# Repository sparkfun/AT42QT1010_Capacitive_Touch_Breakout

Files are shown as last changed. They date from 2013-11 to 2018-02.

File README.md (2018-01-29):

SparkFun Capacitive Touch Breakout - AT42QT101X
====================================

<table class="table table-hover table-striped table-bordered">
  <tr>
   <td><a href="https://www.sparkfun.com/products/12041"><div align="center">SparkFun Capacitive Touch Breakout - AT42QT1010</div></a></td>
  <td><a href="https://www.sparkfun.com/products/14520"><div align="center">SparkFun Capacitive Touch Breakout - AT42QT1011</div></a></center></td>
  </tr>
  <tr>
    <td><div align="center">SparkFun Capacitive Touch Breakout - AT42QT1010 [<a href="https://www.sparkfun.com/products/12041">SEN-12041</a>]</div></td>
    <td><div align="center">SparkFun Capacitive Touch Breakout - AT42QT1011 [<a href="https://www.sparkfun.com/products/14520">SEN-14520</a>]</div></td>
  </tr>
</table>

If you need to add user input without using a button, then a capacitive touch interface might be the answer. The AT42QT1010 and AT42QT1011 Capacitive Touch Breakout boards offer a single capacitive touch button with easy-to-use digital I/O pins. Each model features a slightly different output duration.

Repository Contents
-------------------
* **/Documentation** - Datasheet
* **/Firmware** - Example Arduino sketches
* **/Hardware** - All Eagle design files (.brd, .sch, .STL)
* **/Libraries** - Eagle part library
* **/Production** - Test bed files and production panel files

Documentation
-------------------

* **[Hookup Guide](https://learn.sparkfun.com/tutorials/at42qt101x-capacitive-touch-breakout-hookup-guide)** - Basic hookup guide for the AT42QT1010 and AT42QT1011 Capacitive Touch Breakout.
* *[Hookup Guide (RETIRED)](https://learn.sparkfun.com/tutorials/at42qt1010-capacitive-touch-breakout-hookup-guide) - Basic hookup guide for the AT42QT1010 Capacitive Touch Breakout.*
* **[SparkFun Fritzing repo](https://github.com/sparkfun/Fritzing_Parts)** - Fritzing diagrams for SparkFun products.

Version History
---------------
* **HW_v20.0_FW_v1.0** - Current Version for AT42QT1010 and AT42QT1011 with 8-pin UDFN/USON package.
* *[HW_v1.0_FW_v1.0 (RETIRED)](https://github.com/sparkfun/AT42QT1010_Capacitive_Touch_Breakout/releases/tag/HW_v1.0_FW_v1.0) - Initial release for the AT42QT1010 with 6-Pin SOT23-6 package.*

License Information
-------------------

This product is _**open source**_! 

Please review the LICENSE.md file for license information. 

If you have any questions or concerns on licensing, please contact techsupport@sparkfun.com.

Distributed as-is; no warranty is given.

- Your friends at SparkFun.

_<COLLABORATION CREDIT>_

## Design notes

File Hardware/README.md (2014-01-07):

# What Are these Files?

The .sch and .brd files hare are Eagle CAD schematic and PCB design files.

These files were created with Eagle 6.5.0, you'll need Eagle 6.5 or later to open them up. There is a free, lite, version of Eagle available from [cadsoftusa.com](cadsoftusa.com).

# License

This product is open source! These Eagle files are released under the Creative Commons Share-Alike Attribution license ([CC BY-SA 3.0](http://creativecommons.org/licenses/by-sa/3.0/us/)).

Please use, reuse, and modify these files as you see fit. Please maintain attribution and release anything derivative under the same license.

- Your friends at SparkFun.

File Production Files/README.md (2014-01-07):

These are the production files SparkFun uses for printing PCBs, as well as the Eagle files for our test beds.

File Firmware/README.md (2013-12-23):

* AT42QT1010_Arduino_Example - Simple sketch showing how to use the AT42QT1010 to detect a capacitive touch event

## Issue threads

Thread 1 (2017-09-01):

Prototype quality review

marshalltaylorSFE, 2017-09-01:
## Board:
1.  Rogue tRestrict box floating at (0.965 ,0.385)in.  I think it needs to be removed

2.  NPTH callout belongs in "Special ordering instructions" box, which has schematic symbol.  Layout object goes center under CC attrib

3.  Match name text font and weight on CC in layout.  Names should match style of CC text

4.  Improve measures-

* Move to measures layer
* Text -> vector
* Remove "typ."
* Call out lower holes as well

5.  Jumper text L and F should be separated more and balanced so they don't look like "LF"

6.  Change 19% ratio on connector pins (4 pin header) to 15%

7.  Move large flame off button -- We may have discussed this but looking again, it needs to not be there.  Let me know if you have questions.

## Schematic:
8.  Make flags 0.05 inch, vector, 15%

## General:

9.  Parts not in sparkfun-eagle-libraries or local_library:

* Stand-off
* 1 pin holes (connectors)
* Weird 1 pin SMD pad
* 4-pin right angle SMD connectors
* Power symbols
* Ground symbols

10.  Parts not in bom:

* New PCB (still has old)
* New IC (still has old)

11.  Optional, 4 single pins could be smashed, values removed.
Recommend switching to 4 pin 0.1 inch header rather than 4 1pins

12.  LED color selected as green because it's a button.  This is against standard but not a problem

13.  LED not labeled with purpose- OK, purpose is obvious

edspark, 2017-09-01:
1. Correct
2. Now that I understand what that is, it has been fixed
3. Fixed
4. Fixed
5. Seperated them as best as possible. Added a dash as well.
6. Fixed
7. I put the best fit flame I could on the other side.
8. Persistent Vector setting...never again.,
9. Fixed.
10. Created new PCB but we're keeping current SKU for this revision.  The IC and PCB will stay under their old SKU's until we're ready for REDS.
11. Fixed
12. Werd
13. Actually laughed out loud.

Closed 2017-09-01.

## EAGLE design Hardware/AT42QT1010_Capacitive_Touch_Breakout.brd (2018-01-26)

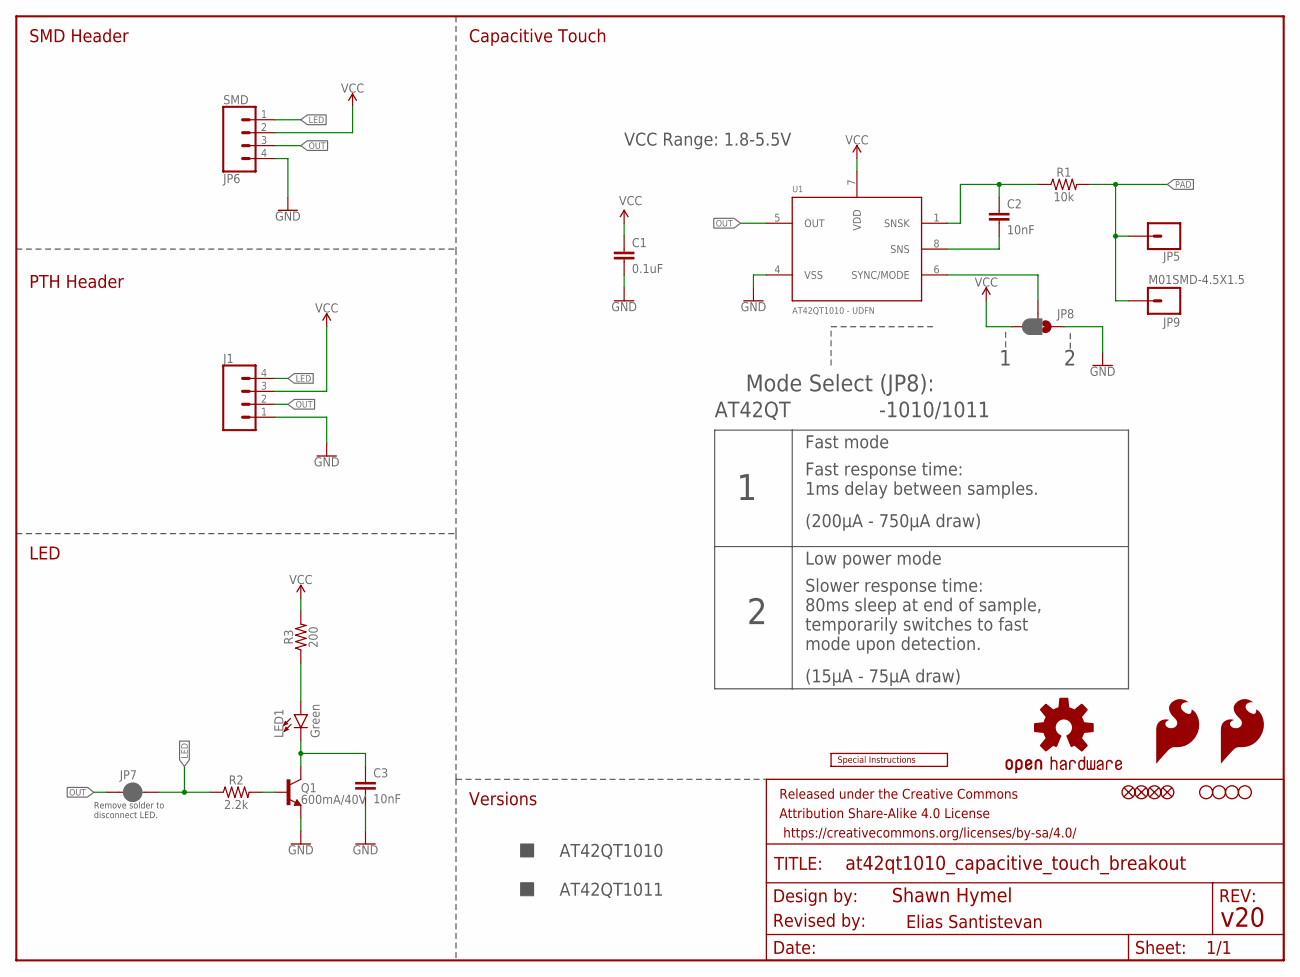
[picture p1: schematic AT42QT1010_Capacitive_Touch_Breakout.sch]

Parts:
C1: 0.1uF; 0603
C2, C3: 10nF; 0603
FID1, FID2, FID3, FID4: FIDUCIAL1X2; FIDUCIAL-1X2
FRAME1: FRAME-LETTER; CREATIVE_COMMONS
J1: CONN_04; 1X04
JP5: CONN_01; 1X01
JP6: SMD; 1X04_SMD_RA_MALE
JP7: JUMPER-SMT_2_NC_PASTE_SILK; SMT-JUMPER_2_NC_PASTE_SILK
JP8: JUMPER-SMT_3_1-NC_PASTE_SILK; SMT-JUMPER_3_1-NC_PASTE_SILK
JP9: M01SMD-4.5X1.5; PAD-1.5X4.5
LED1: Green; LED-1206-BOTTOM
LOGO1, LOGO4: SFE_LOGO_FLAME.2_INCH; SFE_LOGO_FLAME_.2
LOGO2: OSHW-LOGOS; OSHW-LOGO-S
Q1: 600mA/40V; SOT23-3
R1: 10k; 0603
R2: 2.2k; 0603
R3: 200; 0603
STANDOFF1, STANDOFF2, STANDOFF3, STANDOFF4: STAND-OFF
U1: AT42QT1010 - UDFN; UDFN/USON_8_PAD
U$1: SPECIAL_INSTRUCTIONS-ORDERING; ORDERING_INSTRUCTIONS

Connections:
GND: C1.2, C3.2, J1.1, JP6.4, JP8.1, Q1.2 (E), U1.4 (VSS)
LED: J1.4, JP6.1, JP7.2, R2.1
unnamed: JP8.2, U1.6 (SYNC/MODE)
unnamed: C2.2, U1.8 (SNS)
unnamed: C2.1, R1.1, U1.1 (SNSK)
unnamed: Q1.1 (B), R2.2
unnamed: C3.1, LED1.C, Q1.3 (C)
unnamed: LED1.A, R3.1
OUT: J1.2, JP6.3, JP7.1, U1.5 (OUT)
PAD: JP5.1, JP9.P$1, R1.2
VCC: C1.1, J1.3, JP6.2, JP8.3, R3.2, U1.7 (VDD)

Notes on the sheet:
Shawn Hymel
v20
Capacitive Touch
SMD Header
PTH Header
LED
-1010/1011
Fast mode
Fast response time: 1ms delay between samples.
Low power mode
(15µA - 75µA draw)
Slower response time: 80ms sleep at end of sample, temporarily switches to fast mode upon detection.
(200µA - 750µA draw)
Revised by:
Elias Santistevan
VCC Range: 1.8-5.5V
Remove solder to disconnect LED.
Mode Select (JP8):
AT42QT
Versions
AT42QT1010
AT42QT1011

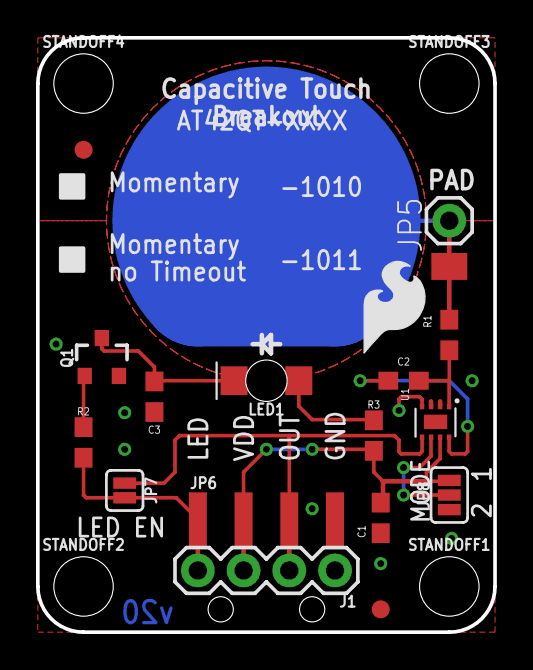
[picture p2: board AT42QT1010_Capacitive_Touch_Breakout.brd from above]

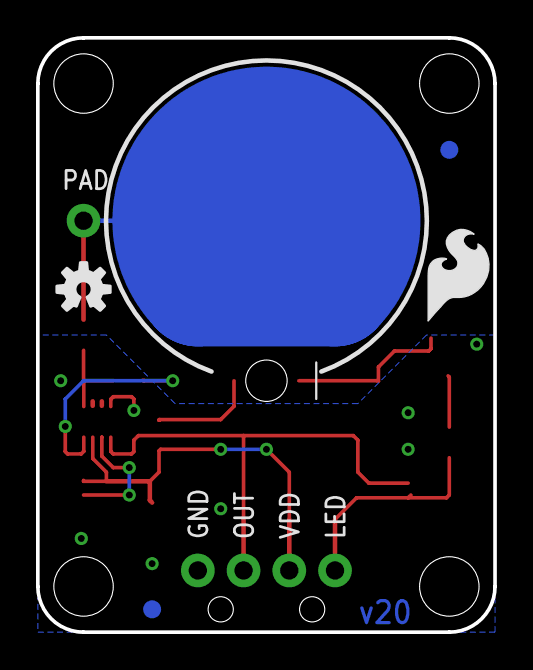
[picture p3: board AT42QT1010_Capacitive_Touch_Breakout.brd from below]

Board: 2 copper layers, 25.4 x 33.0 mm, 28 parts (4 on the bottom side), 11 nets.

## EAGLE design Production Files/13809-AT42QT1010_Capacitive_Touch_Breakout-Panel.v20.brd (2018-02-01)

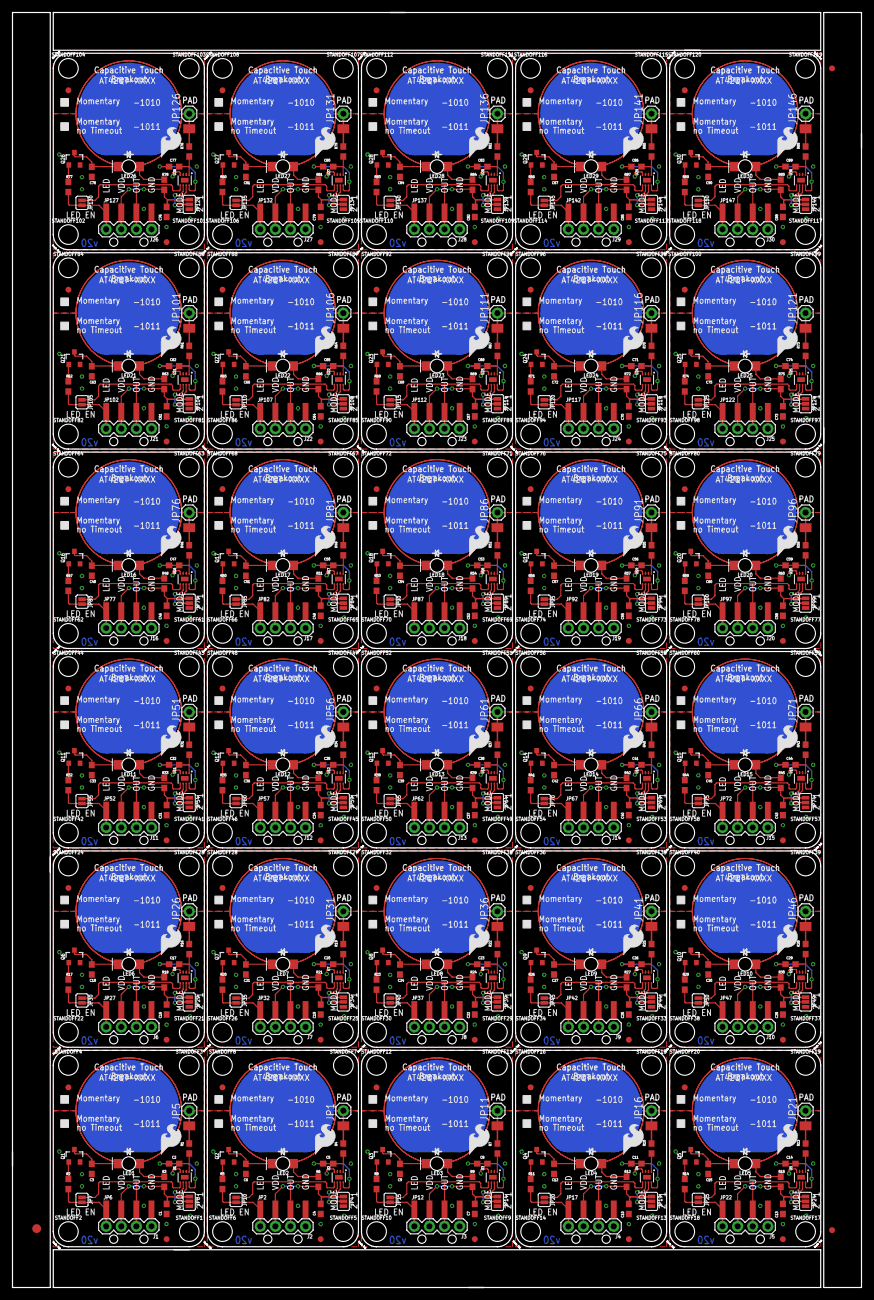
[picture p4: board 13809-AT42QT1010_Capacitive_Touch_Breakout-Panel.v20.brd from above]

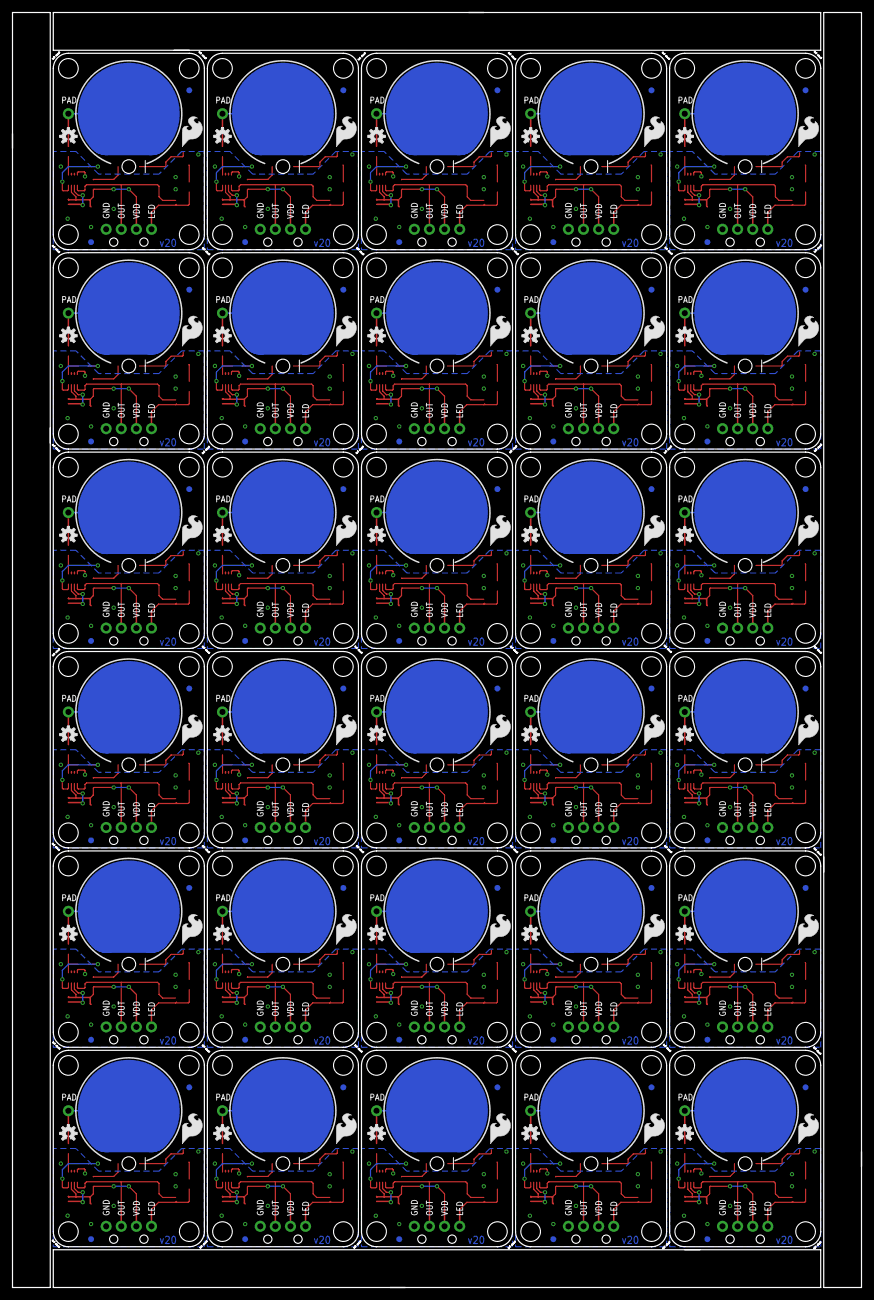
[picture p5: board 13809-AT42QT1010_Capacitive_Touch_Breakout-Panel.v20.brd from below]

Board: 2 copper layers, 142.7 x 214.4 mm, 783 parts (120 on the bottom side), 330 nets.

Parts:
C1, C4, C7, C10, C13, C16, C19, C22, C25, C28, C31, C34, C37, C40, C43, C46, C49, C52, C55, C58, C61, C64, C67, C70, C73, C76, C79, C82, C85, C88: 0.1uF; 0603
C2, C3, C5, C6, C8, C9, C11, C12, C14, C15, C17, C18, C20, C21, C23, C24, C26, C27, C29, C30, C32, C33, C35, C36, C38, C39, C41, C42, C44, C45, C47, C48, C50, C51, C53, C54, C56, C57, C59, C60, C62, C63, C65, C66, C68, C69, C71, C72, C74, C75, C77, C78, C80, C81, C83, C84, C86, C87, C89, C90: 10nF; 0603
E$1: FIDUCIAL-1.5X3
E$7, E$8: FIDUCIAL-1X2
FID1, FID2, FID3, FID4, FID5, FID6, FID7, FID8, FID9, FID10, FID11, FID12, FID13, FID14, FID15, FID16, FID17, FID18, FID19, FID20, FID21, FID22, FID23, FID24, FID25, FID26, FID27, FID28, FID29, FID30, FID31, FID32, FID33, FID34, FID35, FID36, FID37, FID38, FID39, FID40, FID41, FID42, FID43, FID44, FID45, FID46, FID47, FID48, FID49, FID50, FID51, FID52, FID53, FID54, FID55, FID56, FID57, FID58, FID59, FID60, FID61, FID62, FID63, FID64, FID65, FID66, FID67, FID68, FID69, FID70, FID71, FID72, FID73, FID74, FID75, FID76, FID77, FID78, FID79, FID80, FID81, FID82, FID83, FID84, FID85, FID86, FID87, FID88, FID89, FID90, FID91, FID92, FID93, FID94, FID95, FID96, FID97, FID98, FID99, FID100, FID101, FID102, FID103, FID104, FID105, FID106, FID107, FID108, FID109, FID110, FID111, FID112, FID113, FID114, FID115, FID116, FID117, FID118, FID119, FID120: FIDUCIAL1X2; FIDUCIAL-1X2
J1, J2, J3, J4, J5, J6, J7, J8, J9, J10, J11, J12, J13, J14, J15, J16, J17, J18, J19, J20, J21, J22, J23, J24, J25, J26, J27, J28, J29, J30: 1X04
JP1, JP5, JP11, JP16, JP21, JP26, JP31, JP36, JP41, JP46, JP51, JP56, JP61, JP66, JP71, JP76, JP81, JP86, JP91, JP96, JP101, JP106, JP111, JP116, JP121, JP126, JP131, JP136, JP141, JP146: 1X01
JP2, JP6, JP12, JP17, JP22, JP27, JP32, JP37, JP42, JP47, JP52, JP57, JP62, JP67, JP72, JP77, JP82, JP87, JP92, JP97, JP102, JP107, JP112, JP117, JP122, JP127, JP132, JP137, JP142, JP147: SMD; 1X04_SMD_RA_MALE
JP3, JP9, JP13, JP18, JP23, JP28, JP33, JP38, JP43, JP48, JP53, JP58, JP63, JP68, JP73, JP78, JP83, JP88, JP93, JP98, JP103, JP108, JP113, JP118, JP123, JP128, JP133, JP138, JP143, JP148: M01SMD-4.5X1.5; PAD-1.5X4.5
JP4, JP8, JP14, JP19, JP24, JP29, JP34, JP39, JP44, JP49, JP54, JP59, JP64, JP69, JP74, JP79, JP84, JP89, JP94, JP99, JP104, JP109, JP114, JP119, JP124, JP129, JP134, JP139, JP144, JP149: JUMPER-SMT_3_NO_SILK; SMT-JUMPER_3_NO_SILK
JP7, JP10, JP15, JP20, JP25, JP30, JP35, JP40, JP45, JP50, JP55, JP60, JP65, JP70, JP75, JP80, JP85, JP90, JP95, JP100, JP105, JP110, JP115, JP120, JP125, JP130, JP135, JP140, JP145, JP150: JUMPER-SMT_2_NO_SILK; SMT-JUMPER_2_NO_SILK
LED1, LED2, LED3, LED4, LED5, LED6, LED7, LED8, LED9, LED10, LED11, LED12, LED13, LED14, LED15, LED16, LED17, LED18, LED19, LED20, LED21, LED22, LED23, LED24, LED25, LED26, LED27, LED28, LED29, LED30: Green; LED-1206-BOTTOM
LOGO1, LOGO4, LOGO5, LOGO6, LOGO8, LOGO9, LOGO11, LOGO12, LOGO14, LOGO15, LOGO17, LOGO18, LOGO20, LOGO21, LOGO23, LOGO24, LOGO26, LOGO27, LOGO29, LOGO30, LOGO32, LOGO33, LOGO35, LOGO36, LOGO38, LOGO39, LOGO41, LOGO42, LOGO44, LOGO45, LOGO47, LOGO48, LOGO50, LOGO51, LOGO53, LOGO54, LOGO56, LOGO57, LOGO59, LOGO60, LOGO62, LOGO63, LOGO65, LOGO66, LOGO68, LOGO69, LOGO71, LOGO72, LOGO74, LOGO75, LOGO77, LOGO78, LOGO80, LOGO81, LOGO83, LOGO84, LOGO86, LOGO87, LOGO89, LOGO90: SFE_LOGO_FLAME.2_INCH; SFE_LOGO_FLAME_.2
LOGO2, LOGO3, LOGO7, LOGO10, LOGO13, LOGO16, LOGO19, LOGO22, LOGO25, LOGO28, LOGO31, LOGO34, LOGO37, LOGO40, LOGO43, LOGO46, LOGO49, LOGO52, LOGO55, LOGO58, LOGO61, LOGO64, LOGO67, LOGO70, LOGO73, LOGO76, LOGO79, LOGO82, LOGO85, LOGO88: OSHW-LOGOS; OSHW-LOGO-S
Q1, Q2, Q3, Q4, Q5, Q6, Q7, Q8, Q9, Q10, Q11, Q12, Q13, Q14, Q15, Q16, Q17, Q18, Q19, Q20, Q21, Q22, Q23, Q24, Q25, Q26, Q27, Q28, Q29, Q30: 600mA/40V; SOT23-3
R1, R4, R7, R10, R13, R16, R19, R22, R25, R28, R31, R34, R37, R40, R43, R46, R49, R52, R55, R58, R61, R64, R67, R70, R73, R76, R79, R82, R85, R88: 10k; 0603
R2, R5, R8, R11, R14, R17, R20, R23, R26, R29, R32, R35, R38, R41, R44, R47, R50, R53, R56, R59, R62, R65, R68, R71, R74, R77, R80, R83, R86, R89: 2.2k; 0603
R3, R6, R9, R12, R15, R18, R21, R24, R27, R30, R33, R36, R39, R42, R45, R48, R51, R54, R57, R60, R63, R66, R69, R72, R75, R78, R81, R84, R87, R90: 200; 0603
STANDOFF1, STANDOFF2, STANDOFF3, STANDOFF4, STANDOFF5, STANDOFF6, STANDOFF7, STANDOFF8, STANDOFF9, STANDOFF10, STANDOFF11, STANDOFF12, STANDOFF13, STANDOFF14, STANDOFF15, STANDOFF16, STANDOFF17, STANDOFF18, STANDOFF19, STANDOFF20, STANDOFF21, STANDOFF22, STANDOFF23, STANDOFF24, STANDOFF25, STANDOFF26, STANDOFF27, STANDOFF28, STANDOFF29, STANDOFF30, STANDOFF31, STANDOFF32, STANDOFF33, STANDOFF34, STANDOFF35, STANDOFF36, STANDOFF37, STANDOFF38, STANDOFF39, STANDOFF40, STANDOFF41, STANDOFF42, STANDOFF43, STANDOFF44, STANDOFF45, STANDOFF46, STANDOFF47, STANDOFF48, STANDOFF49, STANDOFF50, STANDOFF51, STANDOFF52, STANDOFF53, STANDOFF54, STANDOFF55, STANDOFF56, STANDOFF57, STANDOFF58, STANDOFF59, STANDOFF60, STANDOFF61, STANDOFF62, STANDOFF63, STANDOFF64, STANDOFF65, STANDOFF66, STANDOFF67, STANDOFF68, STANDOFF69, STANDOFF70, STANDOFF71, STANDOFF72, STANDOFF73, STANDOFF74, STANDOFF75, STANDOFF76, STANDOFF77, STANDOFF78, STANDOFF79, STANDOFF80, STANDOFF81, STANDOFF82, STANDOFF83, STANDOFF84, STANDOFF85, STANDOFF86, STANDOFF87, STANDOFF88, STANDOFF89, STANDOFF90, STANDOFF91, STANDOFF92, STANDOFF93, STANDOFF94, STANDOFF95, STANDOFF96, STANDOFF97, STANDOFF98, STANDOFF99, STANDOFF100, STANDOFF101, STANDOFF102, STANDOFF103, STANDOFF104, STANDOFF105, STANDOFF106, STANDOFF107, STANDOFF108, STANDOFF109, STANDOFF110, STANDOFF111, STANDOFF112, STANDOFF113, STANDOFF114, STANDOFF115, STANDOFF116, STANDOFF117, STANDOFF118, STANDOFF119, STANDOFF120: STAND-OFF
U1, U2, U3, U4, U5, U6, U7, U8, U9, U10, U11, U12, U13, U14, U15, U16, U17, U18, U19, U20, U21, U22, U23, U24, U25, U26, U27, U28, U29, U30: AT42QT1010 - UDFN; UDFN/USON_8_PAD

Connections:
GND: C1.2, C3.2, J1.1, JP6.4, JP8.3, Q1.2, U1.4
GND1: C4.2, C6.2, J2.1, JP2.4, JP4.3, Q2.2, U2.4
GND2: C7.2, C9.2, J3.1, JP12.4, JP14.3, Q3.2, U3.4
GND3: C10.2, C12.2, J4.1, JP17.4, JP19.3, Q4.2, U4.4
GND4: C13.2, C15.2, J5.1, JP22.4, JP24.3, Q5.2, U5.4
GND5: C16.2, C18.2, J6.1, JP27.4, JP29.3, Q6.2, U6.4
GND6: C19.2, C21.2, J7.1, JP32.4, JP34.3, Q7.2, U7.4
GND7: C22.2, C24.2, J8.1, JP37.4, JP39.3, Q8.2, U8.4
GND8: C25.2, C27.2, J9.1, JP42.4, JP44.3, Q9.2, U9.4
GND9: C28.2, C30.2, J10.1, JP47.4, JP49.3, Q10.2, U10.4
GND10: C31.2, C33.2, J11.1, JP52.4, JP54.3, Q11.2, U11.4
GND11: C34.2, C36.2, J12.1, JP57.4, JP59.3, Q12.2, U12.4
GND12: C37.2, C39.2, J13.1, JP62.4, JP64.3, Q13.2, U13.4
GND13: C40.2, C42.2, J14.1, JP67.4, JP69.3, Q14.2, U14.4
GND14: C43.2, C45.2, J15.1, JP72.4, JP74.3, Q15.2, U15.4
GND15: C46.2, C48.2, J16.1, JP77.4, JP79.3, Q16.2, U16.4
GND16: C49.2, C51.2, J17.1, JP82.4, JP84.3, Q17.2, U17.4
GND17: C52.2, C54.2, J18.1, JP87.4, JP89.3, Q18.2, U18.4
GND18: C55.2, C57.2, J19.1, JP92.4, JP94.3, Q19.2, U19.4
GND19: C58.2, C60.2, J20.1, JP97.4, JP99.3, Q20.2, U20.4
GND20: C61.2, C63.2, J21.1, JP102.4, JP104.3, Q21.2, U21.4
GND21: C64.2, C66.2, J22.1, JP107.4, JP109.3, Q22.2, U22.4
GND22: C67.2, C69.2, J23.1, JP112.4, JP114.3, Q23.2, U23.4
GND23: C70.2, C72.2, J24.1, JP117.4, JP119.3, Q24.2, U24.4
GND24: C73.2, C75.2, J25.1, JP122.4, JP124.3, Q25.2, U25.4
GND25: C76.2, C78.2, J26.1, JP127.4, JP129.3, Q26.2, U26.4
GND26: C79.2, C81.2, J27.1, JP132.4, JP134.3, Q27.2, U27.4
GND27: C82.2, C84.2, J28.1, JP137.4, JP139.3, Q28.2, U28.4
GND28: C85.2, C87.2, J29.1, JP142.4, JP144.3, Q29.2, U29.4
GND29: C88.2, C90.2, J30.1, JP147.4, JP149.3, Q30.2, U30.4
LED: J1.4, JP6.1, JP7.2, R2.1
LED1: J2.4, JP2.1, JP10.2, R5.1
LED2: J3.4, JP12.1, JP15.2, R8.1
LED3: J4.4, JP17.1, JP20.2, R11.1
LED4: J5.4, JP22.1, JP25.2, R14.1
LED5: J6.4, JP27.1, JP30.2, R17.1
LED6: J7.4, JP32.1, JP35.2, R20.1
LED7: J8.4, JP37.1, JP40.2, R23.1
LED8: J9.4, JP42.1, JP45.2, R26.1
LED9: J10.4, JP47.1, JP50.2, R29.1
LED10: J11.4, JP52.1, JP55.2, R32.1
LED11: J12.4, JP57.1, JP60.2, R35.1
LED12: J13.4, JP62.1, JP65.2, R38.1
LED13: J14.4, JP67.1, JP70.2, R41.1
LED14: J15.4, JP72.1, JP75.2, R44.1
LED15: J16.4, JP77.1, JP80.2, R47.1
LED16: J17.4, JP82.1, JP85.2, R50.1
LED17: J18.4, JP87.1, JP90.2, R53.1
LED18: J19.4, JP92.1, JP95.2, R56.1
LED19: J20.4, JP97.1, JP100.2, R59.1
LED20: J21.4, JP102.1, JP105.2, R62.1
LED21: J22.4, JP107.1, JP110.2, R65.1
LED22: J23.4, JP112.1, JP115.2, R68.1
LED23: J24.4, JP117.1, JP120.2, R71.1
LED24: J25.4, JP122.1, JP125.2, R74.1
LED25: J26.4, JP127.1, JP130.2, R77.1
LED26: J27.4, JP132.1, JP135.2, R80.1
LED27: J28.4, JP137.1, JP140.2, R83.1
LED28: J29.4, JP142.1, JP145.2, R86.1
LED29: J30.4, JP147.1, JP150.2, R89.1
unnamed: C5.2, U2.8
unnamed: C2.2, U1.8
unnamed: C2.1, R1.1, U1.1
unnamed: C5.1, R4.1, U2.1
unnamed: JP8.2, U1.6
unnamed: JP4.2, U2.6
unnamed: Q2.1, R5.2
unnamed: Q1.1, R2.2
unnamed: C3.1, LED1.C, Q1.3
unnamed: LED1.A, R3.1
unnamed: C6.1, LED2.C, Q2.3
unnamed: LED2.A, R6.1
unnamed: C8.2, U3.8
unnamed: C8.1, R7.1, U3.1
unnamed: JP14.2, U3.6
unnamed: Q3.1, R8.2
unnamed: C9.1, LED3.C, Q3.3
unnamed: LED3.A, R9.1
unnamed: C11.2, U4.8
unnamed: C11.1, R10.1, U4.1
unnamed: JP19.2, U4.6
unnamed: Q4.1, R11.2
unnamed: C12.1, LED4.C, Q4.3
unnamed: LED4.A, R12.1
unnamed: C14.2, U5.8
unnamed: C14.1, R13.1, U5.1
unnamed: JP24.2, U5.6
unnamed: Q5.1, R14.2
unnamed: C15.1, LED5.C, Q5.3
unnamed: LED5.A, R15.1
unnamed: C17.2, U6.8
unnamed: C17.1, R16.1, U6.1
unnamed: JP29.2, U6.6
unnamed: Q6.1, R17.2
unnamed: C18.1, LED6.C, Q6.3
unnamed: LED6.A, R18.1
unnamed: C20.2, U7.8
unnamed: C20.1, R19.1, U7.1
unnamed: JP34.2, U7.6
unnamed: Q7.1, R20.2
unnamed: C21.1, LED7.C, Q7.3
unnamed: LED7.A, R21.1
unnamed: C23.2, U8.8
unnamed: C23.1, R22.1, U8.1
unnamed: JP39.2, U8.6
unnamed: Q8.1, R23.2
unnamed: C24.1, LED8.C, Q8.3
unnamed: LED8.A, R24.1
unnamed: C26.2, U9.8
unnamed: C26.1, R25.1, U9.1
unnamed: JP44.2, U9.6
unnamed: Q9.1, R26.2
unnamed: C27.1, LED9.C, Q9.3
unnamed: LED9.A, R27.1
unnamed: C29.2, U10.8
unnamed: C29.1, R28.1, U10.1
unnamed: JP49.2, U10.6
unnamed: Q10.1, R29.2
unnamed: C30.1, LED10.C, Q10.3
unnamed: LED10.A, R30.1
unnamed: C32.2, U11.8
unnamed: C32.1, R31.1, U11.1
unnamed: JP54.2, U11.6
unnamed: Q11.1, R32.2
unnamed: C33.1, LED11.C, Q11.3
unnamed: LED11.A, R33.1
unnamed: C35.2, U12.8
unnamed: C35.1, R34.1, U12.1
unnamed: JP59.2, U12.6
unnamed: Q12.1, R35.2
unnamed: C36.1, LED12.C, Q12.3
unnamed: LED12.A, R36.1
unnamed: C38.2, U13.8
unnamed: C38.1, R37.1, U13.1
unnamed: JP64.2, U13.6
unnamed: Q13.1, R38.2
unnamed: C39.1, LED13.C, Q13.3
unnamed: LED13.A, R39.1
unnamed: C41.2, U14.8
unnamed: C41.1, R40.1, U14.1
unnamed: JP69.2, U14.6
unnamed: Q14.1, R41.2
unnamed: C42.1, LED14.C, Q14.3
unnamed: LED14.A, R42.1
unnamed: C44.2, U15.8
unnamed: C44.1, R43.1, U15.1
unnamed: JP74.2, U15.6
unnamed: Q15.1, R44.2
unnamed: C45.1, LED15.C, Q15.3
unnamed: LED15.A, R45.1
unnamed: C47.2, U16.8
unnamed: C47.1, R46.1, U16.1
unnamed: JP79.2, U16.6
unnamed: Q16.1, R47.2
unnamed: C48.1, LED16.C, Q16.3
unnamed: LED16.A, R48.1
unnamed: C50.2, U17.8
unnamed: C50.1, R49.1, U17.1
unnamed: JP84.2, U17.6
unnamed: Q17.1, R50.2
unnamed: C51.1, LED17.C, Q17.3
unnamed: LED17.A, R51.1
unnamed: C53.2, U18.8
unnamed: C53.1, R52.1, U18.1
unnamed: JP89.2, U18.6
unnamed: Q18.1, R53.2
unnamed: C54.1, LED18.C, Q18.3
unnamed: LED18.A, R54.1
unnamed: C56.2, U19.8
unnamed: C56.1, R55.1, U19.1
unnamed: JP94.2, U19.6
unnamed: Q19.1, R56.2
unnamed: C57.1, LED19.C, Q19.3
unnamed: LED19.A, R57.1
unnamed: C59.2, U20.8
unnamed: C59.1, R58.1, U20.1
unnamed: JP99.2, U20.6
unnamed: Q20.1, R59.2
unnamed: C60.1, LED20.C, Q20.3
unnamed: LED20.A, R60.1
unnamed: C62.2, U21.8
unnamed: C62.1, R61.1, U21.1
unnamed: JP104.2, U21.6
unnamed: Q21.1, R62.2
unnamed: C63.1, LED21.C, Q21.3
unnamed: LED21.A, R63.1
unnamed: C65.2, U22.8
unnamed: C65.1, R64.1, U22.1
unnamed: JP109.2, U22.6
unnamed: Q22.1, R65.2
unnamed: C66.1, LED22.C, Q22.3
unnamed: LED22.A, R66.1
unnamed: C68.2, U23.8
unnamed: C68.1, R67.1, U23.1
unnamed: JP114.2, U23.6
unnamed: Q23.1, R68.2
unnamed: C69.1, LED23.C, Q23.3
unnamed: LED23.A, R69.1
unnamed: C71.2, U24.8
unnamed: C71.1, R70.1, U24.1
unnamed: JP119.2, U24.6
unnamed: Q24.1, R71.2
unnamed: C72.1, LED24.C, Q24.3
unnamed: LED24.A, R72.1
unnamed: C74.2, U25.8
unnamed: C74.1, R73.1, U25.1
unnamed: JP124.2, U25.6
unnamed: Q25.1, R74.2
unnamed: C75.1, LED25.C, Q25.3
unnamed: LED25.A, R75.1
unnamed: C77.2, U26.8
unnamed: C77.1, R76.1, U26.1
unnamed: JP129.2, U26.6
unnamed: Q26.1, R77.2
unnamed: C78.1, LED26.C, Q26.3
unnamed: LED26.A, R78.1
unnamed: C80.2, U27.8
unnamed: C80.1, R79.1, U27.1
unnamed: JP134.2, U27.6
unnamed: Q27.1, R80.2
unnamed: C81.1, LED27.C, Q27.3
unnamed: LED27.A, R81.1
unnamed: C83.2, U28.8
unnamed: C83.1, R82.1, U28.1
unnamed: JP139.2, U28.6
unnamed: Q28.1, R83.2
unnamed: C84.1, LED28.C, Q28.3
unnamed: LED28.A, R84.1
unnamed: C86.2, U29.8
unnamed: C86.1, R85.1, U29.1
unnamed: JP144.2, U29.6
unnamed: Q29.1, R86.2
unnamed: C87.1, LED29.C, Q29.3
unnamed: LED29.A, R87.1
unnamed: C89.2, U30.8
unnamed: C89.1, R88.1, U30.1
unnamed: JP149.2, U30.6
unnamed: Q30.1, R89.2
unnamed: C90.1, LED30.C, Q30.3
unnamed: LED30.A, R90.1
OUT: J1.2, JP6.3, JP7.1, U1.5
OUT1: J2.2, JP2.3, JP10.1, U2.5
OUT2: J3.2, JP12.3, JP15.1, U3.5
OUT3: J4.2, JP17.3, JP20.1, U4.5
OUT4: J5.2, JP22.3, JP25.1, U5.5
OUT5: J6.2, JP27.3, JP30.1, U6.5
OUT6: J7.2, JP32.3, JP35.1, U7.5
OUT7: J8.2, JP37.3, JP40.1, U8.5
OUT8: J9.2, JP42.3, JP45.1, U9.5
OUT9: J10.2, JP47.3, JP50.1, U10.5
OUT10: J11.2, JP52.3, JP55.1, U11.5
OUT11: J12.2, JP57.3, JP60.1, U12.5
OUT12: J13.2, JP62.3, JP65.1, U13.5
OUT13: J14.2, JP67.3, JP70.1, U14.5
OUT14: J15.2, JP72.3, JP75.1, U15.5
OUT15: J16.2, JP77.3, JP80.1, U16.5
OUT16: J17.2, JP82.3, JP85.1, U17.5
OUT17: J18.2, JP87.3, JP90.1, U18.5
OUT18: J19.2, JP92.3, JP95.1, U19.5
OUT19: J20.2, JP97.3, JP100.1, U20.5
OUT20: J21.2, JP102.3, JP105.1, U21.5
OUT21: J22.2, JP107.3, JP110.1, U22.5
OUT22: J23.2, JP112.3, JP115.1, U23.5
OUT23: J24.2, JP117.3, JP120.1, U24.5
OUT24: J25.2, JP122.3, JP125.1, U25.5
OUT25: J26.2, JP127.3, JP130.1, U26.5
OUT26: J27.2, JP132.3, JP135.1, U27.5
OUT27: J28.2, JP137.3, JP140.1, U28.5
OUT28: J29.2, JP142.3, JP145.1, U29.5
OUT29: J30.2, JP147.3, JP150.1, U30.5
PAD: JP5.1, JP9.P$1, R1.2
PAD1: JP1.1, JP3.P$1, R4.2
PAD2: JP11.1, JP13.P$1, R7.2
PAD3: JP16.1, JP18.P$1, R10.2
PAD4: JP21.1, JP23.P$1, R13.2
PAD5: JP26.1, JP28.P$1, R16.2
PAD6: JP31.1, JP33.P$1, R19.2
PAD7: JP36.1, JP38.P$1, R22.2
PAD8: JP41.1, JP43.P$1, R25.2
PAD9: JP46.1, JP48.P$1, R28.2
PAD10: JP51.1, JP53.P$1, R31.2
PAD11: JP56.1, JP58.P$1, R34.2
PAD12: JP61.1, JP63.P$1, R37.2
PAD13: JP66.1, JP68.P$1, R40.2
PAD14: JP71.1, JP73.P$1, R43.2
PAD15: JP76.1, JP78.P$1, R46.2
PAD16: JP81.1, JP83.P$1, R49.2
PAD17: JP86.1, JP88.P$1, R52.2
PAD18: JP91.1, JP93.P$1, R55.2
PAD19: JP96.1, JP98.P$1, R58.2
PAD20: JP101.1, JP103.P$1, R61.2
PAD21: JP106.1, JP108.P$1, R64.2
PAD22: JP111.1, JP113.P$1, R67.2
PAD23: JP116.1, JP118.P$1, R70.2
PAD24: JP121.1, JP123.P$1, R73.2
PAD25: JP126.1, JP128.P$1, R76.2
PAD26: JP131.1, JP133.P$1, R79.2
PAD27: JP136.1, JP138.P$1, R82.2
PAD28: JP141.1, JP143.P$1, R85.2
PAD29: JP146.1, JP148.P$1, R88.2
VCC: C1.1, J1.3, JP6.2, JP8.1, R3.2, U1.7
VCC1: C4.1, J2.3, JP2.2, JP4.1, R6.2, U2.7
VCC2: C7.1, J3.3, JP12.2, JP14.1, R9.2, U3.7
VCC3: C10.1, J4.3, JP17.2, JP19.1, R12.2, U4.7
VCC4: C13.1, J5.3, JP22.2, JP24.1, R15.2, U5.7
VCC5: C16.1, J6.3, JP27.2, JP29.1, R18.2, U6.7
VCC6: C19.1, J7.3, JP32.2, JP34.1, R21.2, U7.7
VCC7: C22.1, J8.3, JP37.2, JP39.1, R24.2, U8.7
VCC8: C25.1, J9.3, JP42.2, JP44.1, R27.2, U9.7
VCC9: C28.1, J10.3, JP47.2, JP49.1, R30.2, U10.7
VCC10: C31.1, J11.3, JP52.2, JP54.1, R33.2, U11.7
VCC11: C34.1, J12.3, JP57.2, JP59.1, R36.2, U12.7
VCC12: C37.1, J13.3, JP62.2, JP64.1, R39.2, U13.7
VCC13: C40.1, J14.3, JP67.2, JP69.1, R42.2, U14.7
VCC14: C43.1, J15.3, JP72.2, JP74.1, R45.2, U15.7
VCC15: C46.1, J16.3, JP77.2, JP79.1, R48.2, U16.7
VCC16: C49.1, J17.3, JP82.2, JP84.1, R51.2, U17.7
VCC17: C52.1, J18.3, JP87.2, JP89.1, R54.2, U18.7
VCC18: C55.1, J19.3, JP92.2, JP94.1, R57.2, U19.7
VCC19: C58.1, J20.3, JP97.2, JP99.1, R60.2, U20.7
VCC20: C61.1, J21.3, JP102.2, JP104.1, R63.2, U21.7
VCC21: C64.1, J22.3, JP107.2, JP109.1, R66.2, U22.7
VCC22: C67.1, J23.3, JP112.2, JP114.1, R69.2, U23.7
VCC23: C70.1, J24.3, JP117.2, JP119.1, R72.2, U24.7
VCC24: C73.1, J25.3, JP122.2, JP124.1, R75.2, U25.7
VCC25: C76.1, J26.3, JP127.2, JP129.1, R78.2, U26.7
VCC26: C79.1, J27.3, JP132.2, JP134.1, R81.2, U27.7
VCC27: C82.1, J28.3, JP137.2, JP139.1, R84.2, U28.7
VCC28: C85.1, J29.3, JP142.2, JP144.1, R87.2, U29.7
VCC29: C88.1, J30.3, JP147.2, JP149.1, R90.2, U30.7

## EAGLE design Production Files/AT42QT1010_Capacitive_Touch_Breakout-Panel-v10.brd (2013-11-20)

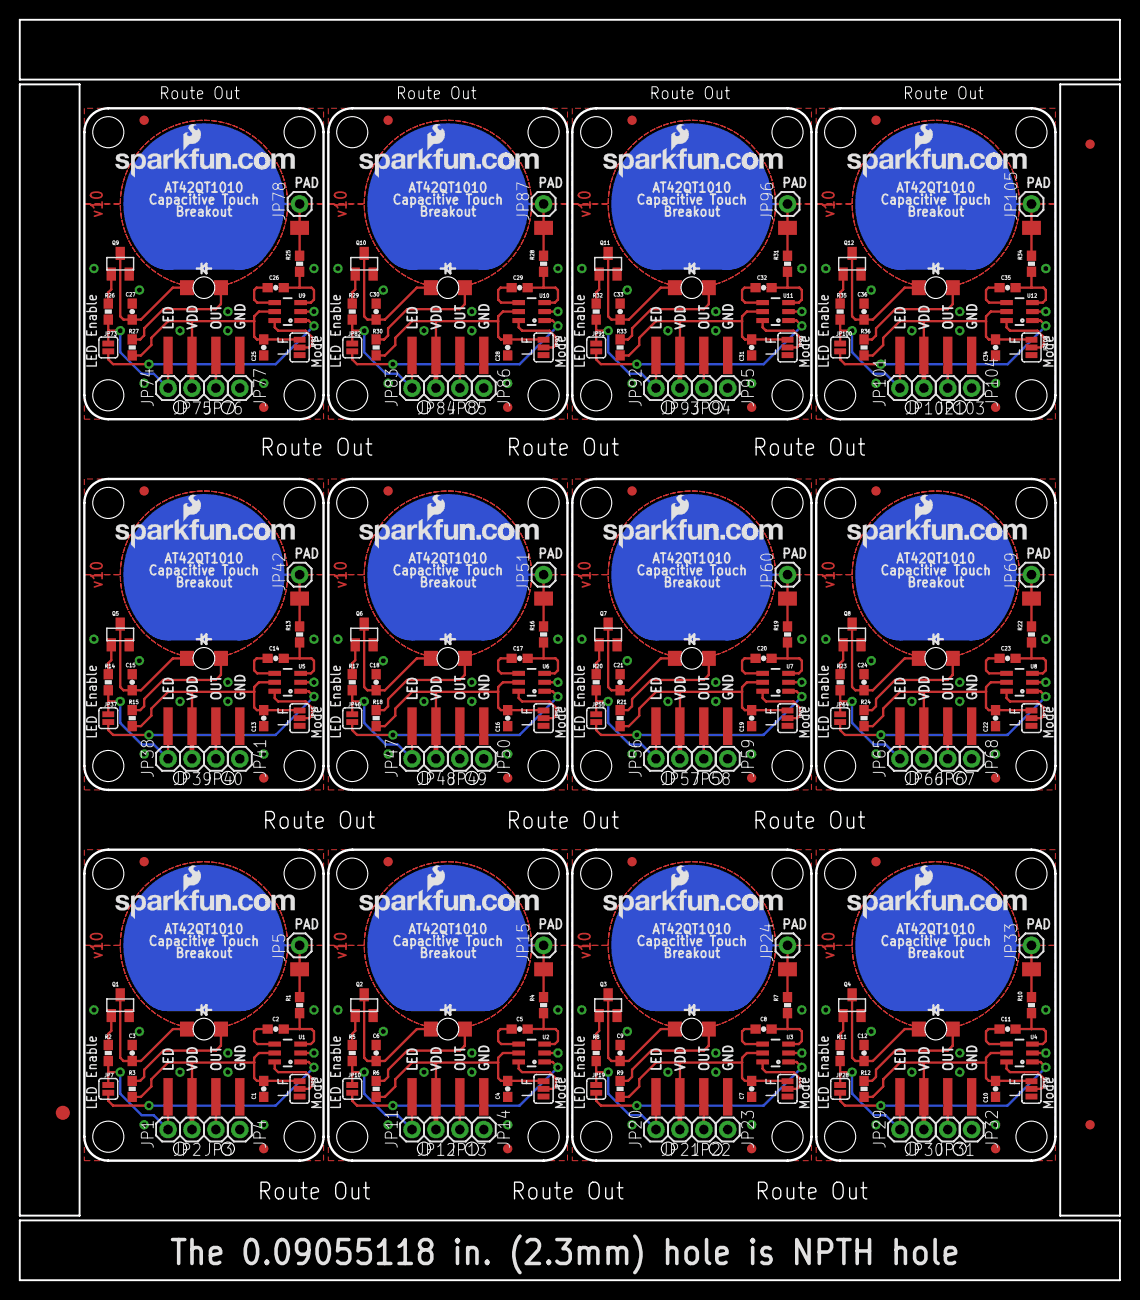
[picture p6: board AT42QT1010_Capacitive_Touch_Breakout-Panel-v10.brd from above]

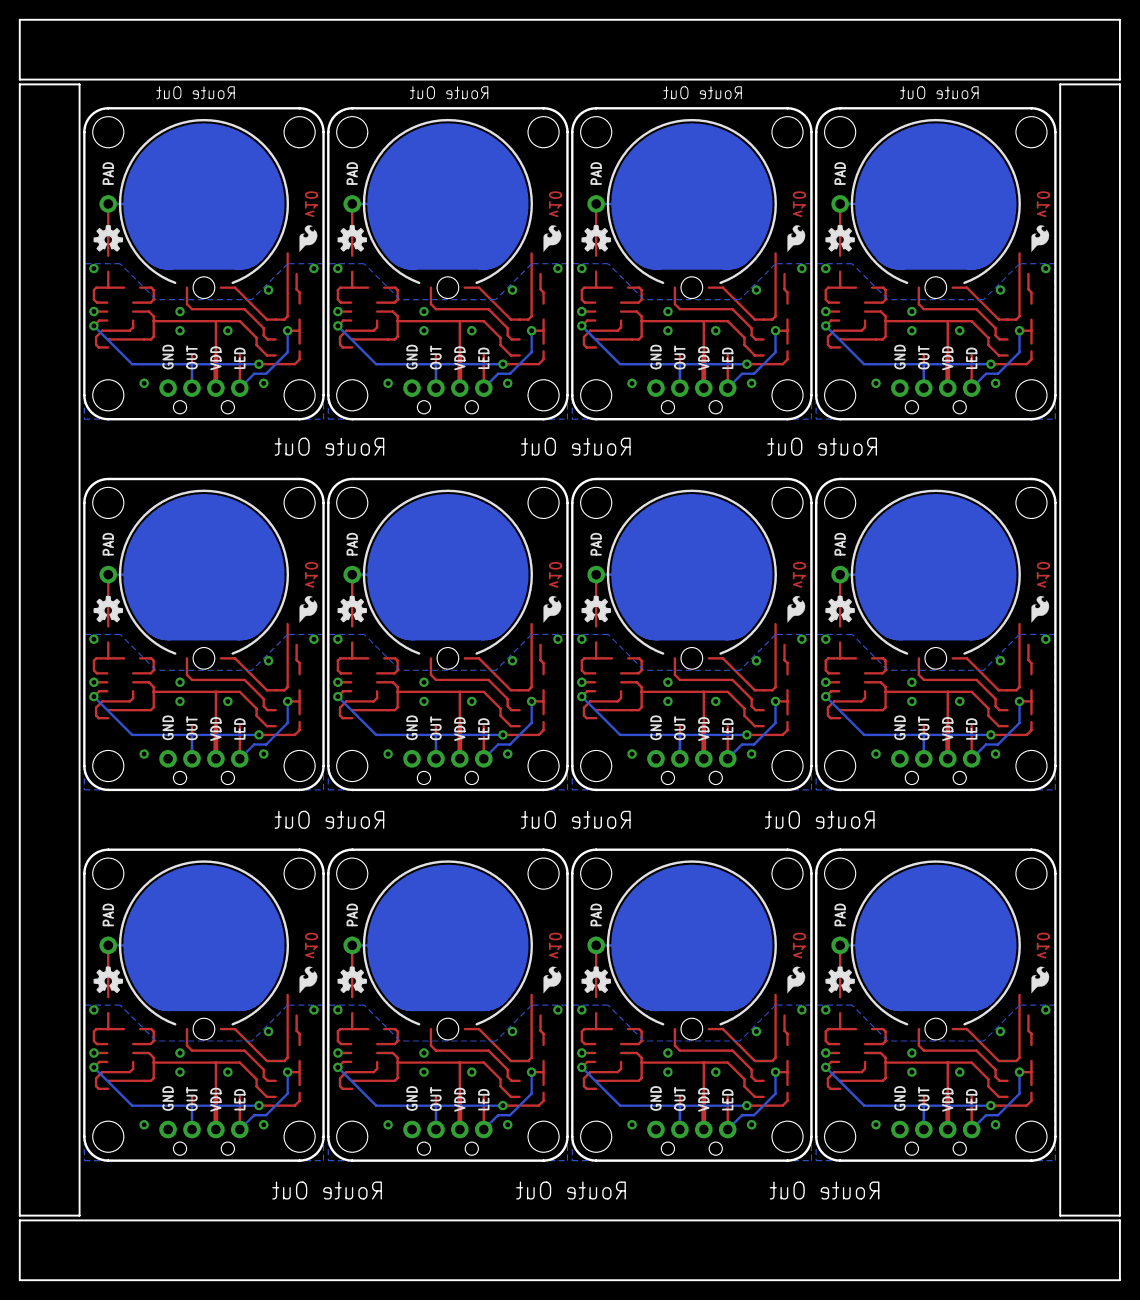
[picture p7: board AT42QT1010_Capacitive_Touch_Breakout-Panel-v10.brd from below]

Board: 2 copper layers, 116.8 x 133.9 mm, 327 parts (24 on the bottom side), 132 nets.

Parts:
C1, C4, C7, C10, C13, C16, C19, C22, C25, C28, C31, C34: 0.1uF; 0603-CAP
C2, C3, C5, C6, C8, C9, C11, C12, C14, C15, C17, C18, C20, C21, C23, C24, C26, C27, C29, C30, C32, C33, C35, C36: 10nF; 0603-CAP
E$1: FIDUCIAL-1.5X3
E$4, E$5: FIDUCIAL-1X2
FID1, FID2, FID3, FID4, FID5, FID6, FID7, FID8, FID9, FID10, FID11, FID12, FID13, FID14, FID15, FID16, FID17, FID18, FID19, FID20, FID21, FID22, FID23, FID24: FIDUCIAL1X2; FIDUCIAL-1X2
JP1, JP2, JP3, JP4, JP5, JP11, JP12, JP13, JP14, JP15, JP20, JP21, JP22, JP23, JP24, JP29, JP30, JP31, JP32, JP33, JP38, JP39, JP40, JP41, JP42, JP47, JP48, JP49, JP50, JP51, JP56, JP57, JP58, JP59, JP60, JP65, JP66, JP67, JP68, JP69, JP74, JP75, JP76, JP77, JP78, JP83, JP84, JP85, JP86, JP87, JP92, JP93, JP94, JP95, JP96, JP101, JP102, JP103, JP104, JP105: M01PTH; 1X01
JP6, JP16, JP25, JP34, JP43, JP52, JP61, JP70, JP79, JP88, JP97, JP106: SMD; 1X04-SMD_LONG
JP7, JP10, JP19, JP28, JP37, JP46, JP55, JP64, JP73, JP82, JP91, JP100: NC; SJ_2S
JP8, JP18, JP27, JP36, JP45, JP54, JP63, JP72, JP81, JP90, JP99, JP108: JUMPER-31-2; SJ_3_PASTE1&2
JP9, JP17, JP26, JP35, JP44, JP53, JP62, JP71, JP80, JP89, JP98, JP107: M01SMD-4.5X1.5; PAD-1.5X4.5
LED1, LED2, LED3, LED4, LED5, LED6, LED7, LED8, LED9, LED10, LED11, LED12: GREEN; LED-1206-BOTTOM
LOGO1, LOGO5, LOGO8, LOGO11, LOGO14, LOGO17, LOGO20, LOGO23, LOGO26, LOGO29, LOGO32, LOGO35: LOGO-SFENEW; SFE-NEW-WEBLOGO
LOGO2, LOGO4, LOGO7, LOGO10, LOGO13, LOGO16, LOGO19, LOGO22, LOGO25, LOGO28, LOGO31, LOGO34: OSHW-LOGOS; OSHW-LOGO-S
LOGO3, LOGO6, LOGO9, LOGO12, LOGO15, LOGO18, LOGO21, LOGO24, LOGO27, LOGO30, LOGO33, LOGO36: LOGO-SFESK; SFE-LOGO-FLAME
Q1, Q2, Q3, Q4, Q5, Q6, Q7, Q8, Q9, Q10, Q11, Q12: NPN; SOT23
R1, R4, R7, R10, R13, R16, R19, R22, R25, R28, R31, R34: 10k; 0603-RES
R2, R5, R8, R11, R14, R17, R20, R23, R26, R29, R32, R35: 2.2k; 0603-RES
R3, R6, R9, R12, R15, R18, R21, R24, R27, R30, R33, R36: 200; 0603-RES
STANDOFF1, STANDOFF2, STANDOFF3, STANDOFF4, STANDOFF5, STANDOFF6, STANDOFF7, STANDOFF8, STANDOFF9, STANDOFF10, STANDOFF11, STANDOFF12, STANDOFF13, STANDOFF14, STANDOFF15, STANDOFF16, STANDOFF17, STANDOFF18, STANDOFF19, STANDOFF20, STANDOFF21, STANDOFF22, STANDOFF23, STANDOFF24, STANDOFF25, STANDOFF26, STANDOFF27, STANDOFF28, STANDOFF29, STANDOFF30, STANDOFF31, STANDOFF32, STANDOFF33, STANDOFF34, STANDOFF35, STANDOFF36, STANDOFF37, STANDOFF38, STANDOFF39, STANDOFF40, STANDOFF41, STANDOFF42, STANDOFF43, STANDOFF44, STANDOFF45, STANDOFF46, STANDOFF47, STANDOFF48: STAND-OFF
U1, U2, U3, U4, U5, U6, U7, U8, U9, U10, U11, U12: AT42QT1010SOT23; SOT23-6

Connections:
GND: C1.2, C3.2, JP4.1, JP6.4, JP8.3, Q1.2, U1.2
GND1: C4.2, C6.2, JP14.1, JP16.4, JP18.3, Q2.2, U2.2
GND2: C7.2, C9.2, JP23.1, JP25.4, JP27.3, Q3.2, U3.2
GND3: C10.2, C12.2, JP32.1, JP34.4, JP36.3, Q4.2, U4.2
GND4: C13.2, C15.2, JP41.1, JP43.4, JP45.3, Q5.2, U5.2
GND5: C16.2, C18.2, JP50.1, JP52.4, JP54.3, Q6.2, U6.2
GND6: C19.2, C21.2, JP59.1, JP61.4, JP63.3, Q7.2, U7.2
GND7: C22.2, C24.2, JP68.1, JP70.4, JP72.3, Q8.2, U8.2
GND8: C25.2, C27.2, JP77.1, JP79.4, JP81.3, Q9.2, U9.2
GND9: C28.2, C30.2, JP86.1, JP88.4, JP90.3, Q10.2, U10.2
GND10: C31.2, C33.2, JP95.1, JP97.4, JP99.3, Q11.2, U11.2
GND11: C34.2, C36.2, JP104.1, JP106.4, JP108.3, Q12.2, U12.2
LED: JP1.1, JP6.1, JP7.2, R2.1
LED1: JP10.2, JP11.1, JP16.1, R5.1
LED2: JP19.2, JP20.1, JP25.1, R8.1
LED3: JP28.2, JP29.1, JP34.1, R11.1
LED4: JP37.2, JP38.1, JP43.1, R14.1
LED5: JP46.2, JP47.1, JP52.1, R17.1
LED6: JP55.2, JP56.1, JP61.1, R20.1
LED7: JP64.2, JP65.1, JP70.1, R23.1
LED8: JP73.2, JP74.1, JP79.1, R26.1
LED9: JP82.2, JP83.1, JP88.1, R29.1
LED10: JP91.2, JP92.1, JP97.1, R32.1
LED11: JP100.2, JP101.1, JP106.1, R35.1
unnamed: C5.2, U2.4
unnamed: C5.1, R4.1, U2.3
unnamed: JP18.2, U2.6
unnamed: C2.2, U1.4
unnamed: C2.1, R1.1, U1.3
unnamed: Q2.1, R5.2
unnamed: JP8.2, U1.6
unnamed: C6.1, LED2.C, Q2.3
unnamed: LED2.A, R6.1
unnamed: Q1.1, R2.2
unnamed: C3.1, LED1.C, Q1.3
unnamed: LED1.A, R3.1
unnamed: C8.2, U3.4
unnamed: C8.1, R7.1, U3.3
unnamed: JP27.2, U3.6
unnamed: Q3.1, R8.2
unnamed: C9.1, LED3.C, Q3.3
unnamed: LED3.A, R9.1
unnamed: C11.2, U4.4
unnamed: C11.1, R10.1, U4.3
unnamed: JP36.2, U4.6
unnamed: Q4.1, R11.2
unnamed: C12.1, LED4.C, Q4.3
unnamed: LED4.A, R12.1
unnamed: C14.2, U5.4
unnamed: C14.1, R13.1, U5.3
unnamed: JP45.2, U5.6
unnamed: Q5.1, R14.2
unnamed: C15.1, LED5.C, Q5.3
unnamed: LED5.A, R15.1
unnamed: C17.2, U6.4
unnamed: C17.1, R16.1, U6.3
unnamed: JP54.2, U6.6
unnamed: Q6.1, R17.2
unnamed: C18.1, LED6.C, Q6.3
unnamed: LED6.A, R18.1
unnamed: C20.2, U7.4
unnamed: C20.1, R19.1, U7.3
unnamed: JP63.2, U7.6
unnamed: Q7.1, R20.2
unnamed: C21.1, LED7.C, Q7.3
unnamed: LED7.A, R21.1
unnamed: C23.2, U8.4
unnamed: C23.1, R22.1, U8.3
unnamed: JP72.2, U8.6
unnamed: Q8.1, R23.2
unnamed: C24.1, LED8.C, Q8.3
unnamed: LED8.A, R24.1
unnamed: C26.2, U9.4
unnamed: C26.1, R25.1, U9.3
unnamed: JP81.2, U9.6
unnamed: Q9.1, R26.2
unnamed: C27.1, LED9.C, Q9.3
unnamed: LED9.A, R27.1
unnamed: C29.2, U10.4
unnamed: C29.1, R28.1, U10.3
unnamed: JP90.2, U10.6
unnamed: Q10.1, R29.2
unnamed: C30.1, LED10.C, Q10.3
unnamed: LED10.A, R30.1
unnamed: C32.2, U11.4
unnamed: C32.1, R31.1, U11.3
unnamed: JP99.2, U11.6
unnamed: Q11.1, R32.2
unnamed: C33.1, LED11.C, Q11.3
unnamed: LED11.A, R33.1
unnamed: C35.2, U12.4
unnamed: C35.1, R34.1, U12.3
unnamed: JP108.2, U12.6
unnamed: Q12.1, R35.2
unnamed: C36.1, LED12.C, Q12.3
unnamed: LED12.A, R36.1
OUT: JP3.1, JP6.3, JP7.1, U1.1
OUT1: JP10.1, JP13.1, JP16.3, U2.1
OUT2: JP19.1, JP22.1, JP25.3, U3.1
OUT3: JP28.1, JP31.1, JP34.3, U4.1
OUT4: JP37.1, JP40.1, JP43.3, U5.1
OUT5: JP46.1, JP49.1, JP52.3, U6.1
OUT6: JP55.1, JP58.1, JP61.3, U7.1
OUT7: JP64.1, JP67.1, JP70.3, U8.1
OUT8: JP73.1, JP76.1, JP79.3, U9.1
OUT9: JP82.1, JP85.1, JP88.3, U10.1
OUT10: JP91.1, JP94.1, JP97.3, U11.1
OUT11: JP100.1, JP103.1, JP106.3, U12.1
PAD: JP5.1, JP9.P$1, R1.2
PAD1: JP15.1, JP17.P$1, R4.2
PAD2: JP24.1, JP26.P$1, R7.2
PAD3: JP33.1, JP35.P$1, R10.2
PAD4: JP42.1, JP44.P$1, R13.2
PAD5: JP51.1, JP53.P$1, R16.2
PAD6: JP60.1, JP62.P$1, R19.2
PAD7: JP69.1, JP71.P$1, R22.2
PAD8: JP78.1, JP80.P$1, R25.2
PAD9: JP87.1, JP89.P$1, R28.2
PAD10: JP96.1, JP98.P$1, R31.2
PAD11: JP105.1, JP107.P$1, R34.2
VCC: C1.1, JP2.1, JP6.2, JP8.1, R3.2, U1.5
VCC1: C4.1, JP12.1, JP16.2, JP18.1, R6.2, U2.5
VCC2: C7.1, JP21.1, JP25.2, JP27.1, R9.2, U3.5
VCC3: C10.1, JP30.1, JP34.2, JP36.1, R12.2, U4.5
VCC4: C13.1, JP39.1, JP43.2, JP45.1, R15.2, U5.5
VCC5: C16.1, JP48.1, JP52.2, JP54.1, R18.2, U6.5
VCC6: C19.1, JP57.1, JP61.2, JP63.1, R21.2, U7.5
VCC7: C22.1, JP66.1, JP70.2, JP72.1, R24.2, U8.5
VCC8: C25.1, JP75.1, JP79.2, JP81.1, R27.2, U9.5
VCC9: C28.1, JP84.1, JP88.2, JP90.1, R30.2, U10.5
VCC10: C31.1, JP93.1, JP97.2, JP99.1, R33.2, U11.5
VCC11: C34.1, JP102.1, JP106.2, JP108.1, R36.2, U12.5

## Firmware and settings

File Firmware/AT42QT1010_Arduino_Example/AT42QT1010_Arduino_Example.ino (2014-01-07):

/*
 12-23-2013
 SparkFun Electronics 2013
 Shawn Hymel

 This code is public domain but you buy me a beer if you use this 
 and we meet someday (Beerware license).

 Description:

 This sketch shows how to use the SparkFun AT42QT1010 Breakout
 Board. If you touch the Capacitive Touch area on the breakout
 board, the LED attached to the Arduino will light up (in addition
 to the LED on the AT42QT1010 breakout board).
 
 Simply connect power and ground to the breakout board,
 and the AT42QT1010 handles all the capacitive touch functions.
 By default, the board will light up the green LED when the pad
 is touched. A wire may also be connected from OUT on the
 breakout board to a digital input pin on an Arduino. This signal
 is normally LOW but goes HIGH on a touch detection. 
 
 The "LED Enable" solder jumper may be de-soldered in order to
 control the LED directly from the LED pin. This is useful if you
 want to light up a button that the user needs to push.

 Hardware connections:
 
 Uno Pin    AT42QT1010 Board  Function
 
 +5V        VDD               Power supply
 GND        GND               Ground
 2          OUT               Capacitive touch state output
 */

// Constants
const int TOUCH_BUTTON_PIN = 2;  // Input pin for touch state
const int LED_PIN = 13;          // Pin number for LED

// Global Variables
int buttonState = 0;             // Variable for reading button

void setup() {
  
  // Configure button pin as input 
  pinMode(TOUCH_BUTTON_PIN, INPUT);
  
  // Configure LED pin as output
  pinMode(LED_PIN, OUTPUT);
  
}

void loop() {
  
  // Read the state of the capacitive touch board
  buttonState = digitalRead(TOUCH_BUTTON_PIN);
  
  // If a touch is detected, turn on the LED
  if (buttonState == HIGH) {
    digitalWrite(LED_PIN, HIGH);
  } else {
    digitalWrite(LED_PIN, LOW);
  }
}

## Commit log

2013-08-23 Created schematic
    [AT42QT1010_Capacitive_Touch_Breakout.sch]
2013-08-24 started layout
    [AT42QT1010_Capacitive_Touch_Breakout.brd, AT42QT1010_Capacitive_Touch_Breakout.sch]
2013-08-24 Prototype board ready for review
    [AT42QT1010_Capacitive_Touch_Breakout.brd, AT42QT1010_Capacitive_Touch_Breakout.sch]
2013-08-24 Moved vias - Prototype board ready for review
    [AT42QT1010_Capacitive_Touch_Breakout.brd]
2013-08-26 Revert "Moved vias - Prototype board ready for review"
    This reverts commit 4ac3947f8fe1c0e8c4ceb60569549ddd8cbc65d4.
    [AT42QT1010_Capacitive_Touch_Breakout.brd]
2013-08-27 Fixed issues from design review
    [AT42QT1010_Capacitive_Touch_Breakout.brd, AT42QT1010_Capacitive_Touch_Breakout.sch]
2013-08-27 Redo layout to allow for small board and header
    [AT42QT1010_Capacitive_Touch_Breakout.brd]
2013-08-27 Fixed teh borked EAGLE files.
    [AT42QT1010_Capacitive_Touch_Breakout.brd, AT42QT1010_Capacitive_Touch_Breakout.sch]
2013-08-27 Added flag to schematic wire
    [AT42QT1010_Capacitive_Touch_Breakout.brd, AT42QT1010_Capacitive_Touch_Breakout.sch]
2013-08-27 Board ready for prototype run
    [AT42QT1010_Capacitive_Touch_Breakout.brd]
2013-10-01 Moved straight headers down and moved LED via away from mounting hole.
    [AT42QT1010_Capacitive_Touch_Breakout.brd, AT42QT1010_Capacitive_Touch_Breakout.sch]
2013-10-02 Moved headers, added LED polarity, extended pads on SMT headers
    [AT42QT1010_Capacitive_Touch_Breakout.brd, AT42QT1010_Capacitive_Touch_Breakout.sch]
2013-10-16 Added lines to sch, added LED polarity marker, added notes for Modes on sch and brd, rounded corners
    [AT42QT1010_Capacitive_Touch_Breakout.brd, AT42QT1010_Capacitive_Touch_Breakout.sch]
2013-10-16 Moved section labels in sch
    [AT42QT1010_Capacitive_Touch_Breakout.brd, AT42QT1010_Capacitive_Touch_Breakout.sch]
2013-10-16 Removed gnd island in brd
    [AT42QT1010_Capacitive_Touch_Breakout.brd]
2013-11-09 Ready for red board review
    [AT42QT1010_Capacitive_Touch_Breakout.brd, AT42QT1010_Capacitive_Touch_Breakout.sch]
2013-11-15 Updated connectors library with 1X04-SMD_LONG. Should be no changes in schematic/layout.
    [AT42QT1010_Capacitive_Touch_Breakout.brd, AT42QT1010_Capacitive_Touch_Breakout.sch]
2013-11-20 Created Panel
    I Included the note about the NPTH hole on the framework of the panel.
    Big Silk, shouldn't miss it.
    [AT42QT1010_Capacitive_Touch_Breakout-Panel-v10.brd]
2013-12-23 Added example Arduino sketch
2014-01-07 Added pdf version of schematic
2017-07-14 Replaced old IC package with new smaller package
    [AT42QT1010_Capacitive_Touch_Breakout.brd, AT42QT1010_Capacitive_Touch_Breakout.sch]
2017-07-18 Orphans, Schematic changes
    Adjusted some traces, updated CC frame, added VCC range, updated jumpers
    to a more current package, added fiducials to underside, added Sparkfun
    label to schematic.
    [AT42QT1010_Capacitive_Touch_Breakout.brd, AT42QT1010_Capacitive_Touch_Breakout.sch]
2017-08-25 Silk, 0603 packages, flipped header
    Fixed some redundant silk, replaced all 0603 packages with newer
    versions, and flipped the 4 pin header to align with the PTH headers on
    the schematic.
    [AT42QT1010_Capacitive_Touch_Breakout.brd, AT42QT1010_Capacitive_Touch_Breakout.sch]
2017-08-28 Update from Review Feedback
    Added better text to the schematic to explain slow/fast mode. Got rid of
    an uneccesary VCC trace, added more gnd vias and changed all vias to 15
    mil for consistency.
    [AT42QT1010_Capacitive_Touch_Breakout.brd, AT42QT1010_Capacitive_Touch_Breakout.sch]
2017-09-01 Checklist Changes, ready for review.
    [AT42QT1010_Capacitive_Touch_Breakout.brd, AT42QT1010_Capacitive_Touch_Breakout.sch]
2017-09-01 Updated AT42QT Package description and Production ID.
    [AT42QT1010_Capacitive_Touch_Breakout.brd, AT42QT1010_Capacitive_Touch_Breakout.sch]
2017-09-01 Moved new part to local library "local_parts" and updated transistor
    [AT42QT1010_Capacitive_Touch_Breakout.brd, AT42QT1010_Capacitive_Touch_Breakout.sch]
2017-09-01 Fixed issues from double check
    [AT42QT1010_Capacitive_Touch_Breakout.brd, AT42QT1010_Capacitive_Touch_Breakout.sch]
2017-09-01 Missed a flag in the schematic.
    [AT42QT1010_Capacitive_Touch_Breakout.sch]
2017-09-28 Made space for and added version jumpers
    [AT42QT1010_Capacitive_Touch_Breakout.brd, AT42QT1010_Capacitive_Touch_Breakout.sch]
2017-10-11 Revert "Missed a flag in the schematic."
    This reverts commit deb221090333cbab456252bc5ecb8422d1ff9cbc.
    [AT42QT1010_Capacitive_Touch_Breakout.sch]
2017-10-11 Revert "Made space for and added version jumpers"
    This reverts commit 0dfcf3fd33d472c1ea0c54a853371dbd5ffd3b83.
    [AT42QT1010_Capacitive_Touch_Breakout.brd, AT42QT1010_Capacitive_Touch_Breakout.sch]
2017-10-11 New branch due to the large changes to the existing direction of the product
    [AT42QT1010_Capacitive_Touch_Breakout.brd, AT42QT1010_Capacitive_Touch_Breakout.sch]
2017-10-11 Fixing text, changing version number
    ...in preparation for review.
    [AT42QT1010_Capacitive_Touch_Breakout.brd, AT42QT1010_Capacitive_Touch_Breakout.sch]
2017-10-12 Better Labels, replaced jumpers
    Much better labels for the selection of low power/fast mode and 15min
    timeout vs. no timeout. I also created a device that is a square solder
    pad for production to use to identify different versions of the board.
    [AT42QT1010_Capacitive_Touch_Breakout.brd, AT42QT1010_Capacitive_Touch_Breakout.sch]
2017-10-13 Moved silk around.
    [AT42QT1010_Capacitive_Touch_Breakout.brd, AT42QT1010_Capacitive_Touch_Breakout.sch]
2017-10-13 Changed blank solder pads to solid slik boxes
    [AT42QT1010_Capacitive_Touch_Breakout.brd, AT42QT1010_Capacitive_Touch_Breakout.sch]
2017-10-13 Checklist fixes, ready for double check.
    [AT42QT1010_Capacitive_Touch_Breakout.brd]
2017-10-19 Issues from double check Fixed
    [AT42QT1010_Capacitive_Touch_Breakout.brd, AT42QT1010_Capacitive_Touch_Breakout.sch]
2017-11-27 Update for REDS review
    [AT42QT1010_Capacitive_Touch_Breakout.brd, AT42QT1010_Capacitive_Touch_Breakout.sch]
2017-11-27 Minor adjustment before double check
    Moved fiducials so that it does not overlay silk, adjusted the "PAD"
    silk to be better aligned with the through hole.
    [AT42QT1010_Capacitive_Touch_Breakout.brd]
2017-11-28 Post Double Check fixes
    Moved fiducials again, fixed LED pin routing, deleted strange tRestrict
    around LED pin, and adjusted some silk once more.
    [AT42QT1010_Capacitive_Touch_Breakout.brd]
2018-01-18 Changed jumpers to be closed jumpers
    [AT42QT1010_Capacitive_Touch_Breakout.brd, AT42QT1010_Capacitive_Touch_Breakout.sch]
2018-02-01 TCream added to LED_EN and MODE jumpers
    [13809-AT42QT1010_Capacitive_Touch_Breakout-Panel.v20.brd]

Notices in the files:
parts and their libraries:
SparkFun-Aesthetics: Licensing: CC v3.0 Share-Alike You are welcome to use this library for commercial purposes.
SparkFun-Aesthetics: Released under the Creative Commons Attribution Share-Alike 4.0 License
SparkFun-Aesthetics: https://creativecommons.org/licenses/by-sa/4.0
